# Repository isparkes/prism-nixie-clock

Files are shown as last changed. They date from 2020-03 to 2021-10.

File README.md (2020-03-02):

# Prism Large Tube Nixie Clock
This is the board design for the "Prism" 6-digit Nixie Clock based on the ESP-8266 with NeoPixel LED backlights

## Links
This code comes from:       https://bitbucket.org/isparkes/prism-firmware/
The Hardware:               https://bitbucket.org/isparkes/prism-direct-drive-in-18/

My Shop:                    https://www.nixieclock.biz/Store.html
Manuals:                    https://www.nixieclock.biz/Manuals.html

#### Features:
- Open source Hard and Software 
- Internet connected with the ESP8266
- Real Time Clock interface for backup
- Configuration stored in EEPROM
- RGB Back lighting
- Automatic linear dimming using light sensor

**Instruction and User Manuals (including schematic) can be found at:** [https://www.nixieclock.biz/Manuals.html](https://www.nixieclock.biz/Manuals.html)

You can buy this from: [https://www.nixieclock.biz/Store.html](https://www.nixieclock.biz/Store.html)

YouTube channel: [Ian's YouTube Channel](https://www.youtube.com/channel/UCiC34G8yl0mN2BK-LzPw0ew?view_as=subscriber)

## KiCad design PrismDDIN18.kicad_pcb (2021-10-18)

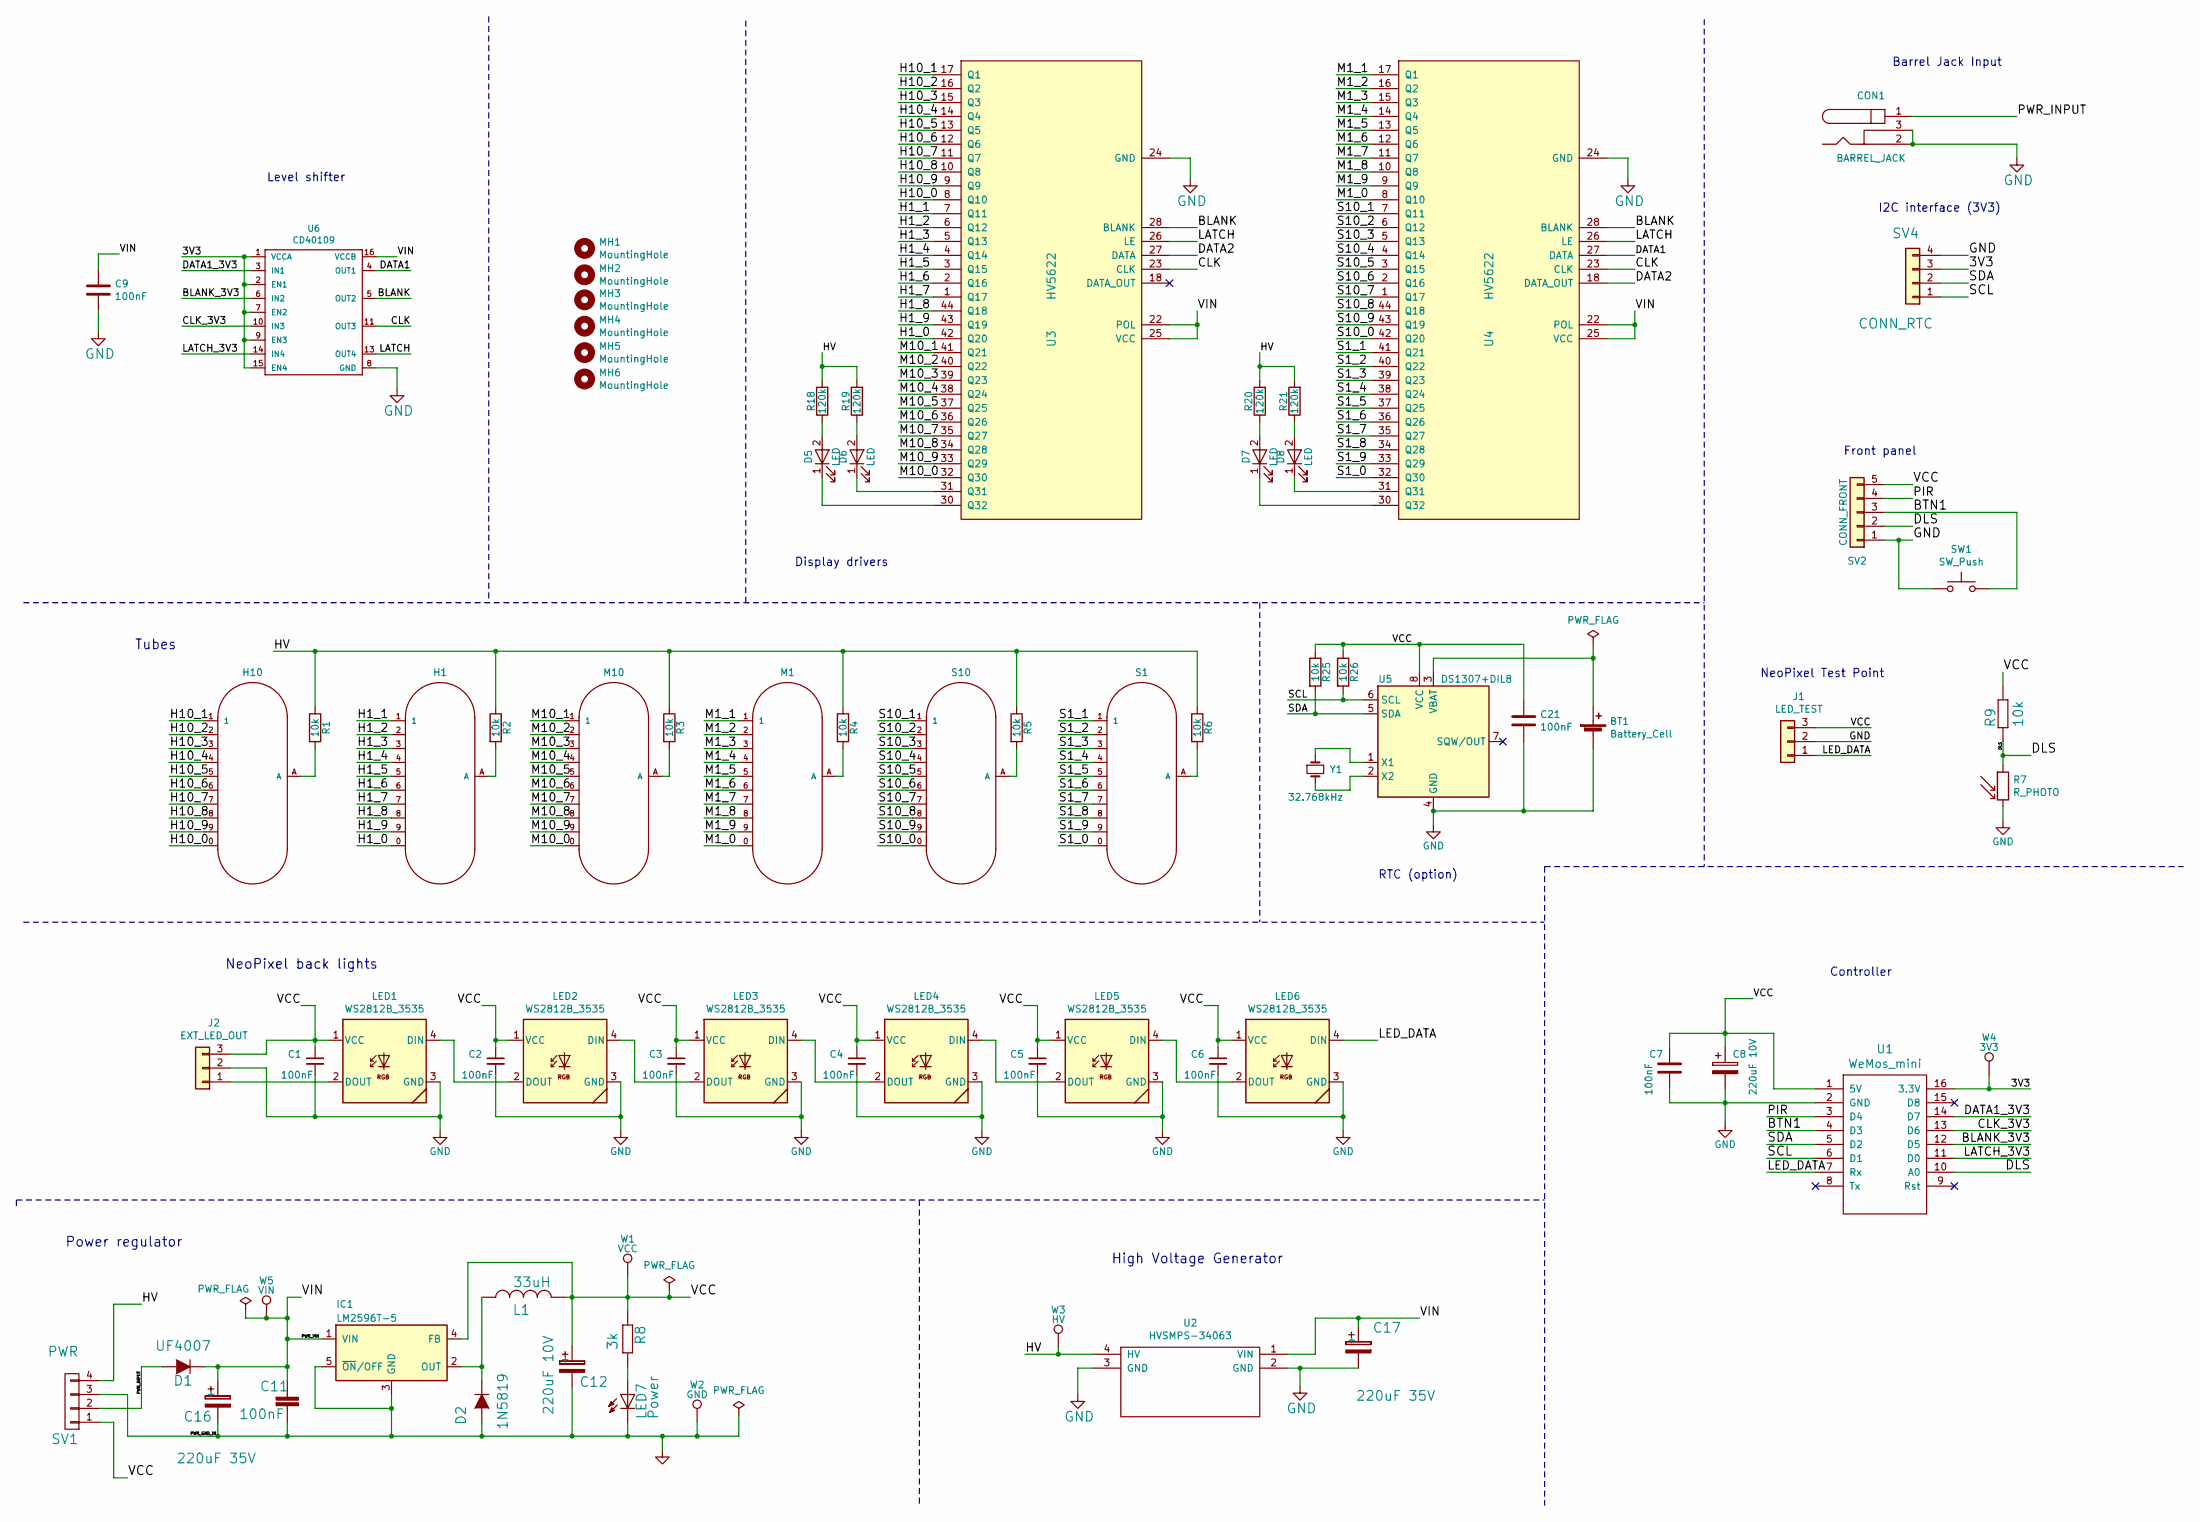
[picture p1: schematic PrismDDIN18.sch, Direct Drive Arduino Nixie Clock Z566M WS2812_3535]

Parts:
BT1: Battery_Cell; CR1220-CoinCell
C1, C2, C3, C4, C5, C6: 100nF; C_1206_3216Metric
C7, C9, C11, C21: 100nF; C025-024X044
C8, C12: 220uF 10V; C_Radial_D6.3_L11.2_P2.5
C16, C17: 220uF 35V; C_Radial_D6.3_L11.2_P2.5
CON1: BARREL_JACK
D1: UF4007; Diode_DO-41_1N4001
D2: 1N5819; Diode_DO-41_1N4001
D5, D6, D7, D8: LED; LED-5MM-Centred
H1, H10: Z566M; IN-18-standoff-pins
IC1: LM2596T-5; TO220-5A_H
J1: LED_TEST; Header_MA03-1_Small
J2: EXT_LED_OUT; Header_MA03-1_Small
L1: 33uH; Inductor-33mH-TH-SMD
LED1, LED2, LED3, LED4, LED5, LED6: WS2812B_3535; WS2812B-SmallPads
LED7: Power; LED_3MM
M1, M10: Z566M; IN-18-standoff-pins
MH1, MH2, MH3, MH4, MH5, MH6: MountingHole; MountingHole_3.2mm_M3
R1, R2, R3, R4, R5, R6: 10k; R_Short_P7.62mm_Horizontal
R7: R_PHOTO; C_Naked
R8: 3k; R-0207_2V
R9, R25, R26: 10k; R-0207_2V
R18, R19, R20, R21: 120k; R_Short_P7.62mm_Horizontal
S1, S10: Z566M; IN-18-standoff-pins
SV1: PWR; Header_MA04-1
SV2: CONN_FRONT; Header_MA05-1
SV4: CONN_RTC; Header_MA04-1
SW1: SW_Push; SW_SPST_CK_RS282G05A3
U1: WeMos_mini; WeMos_D1_mini_board_simple
U2: HVSMPS-34063
U3, U4: HV5622; PLCC44
U5: DS1307+DIL8; DIP-8_W7.62mm
U6: CD40109; DIP-16_W7.62mm
W1: VCC; TESTPAD_P1-13
W2: GND; TESTPAD_P1-13
W3: HV; TESTPAD_P1-13
W4: 3V3; TESTPAD_P1-13
W5: VIN; TESTPAD_P1-13
Y1: 32.768kHz; Crystal_DS10_d1.0mm_l4.3mm_Horizontal

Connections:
/3V3: SV4.3, U1.16 (3.3V), U6.1 (VCCA), U6.2 (EN1), U6.7 (EN2), U6.9 (EN3), U6.15 (EN4), W4.1
/BLANK: U3.28 (BLANK), U4.28 (BLANK), U6.5 (OUT2)
/BLANK_3V3: U1.12 (D5), U6.6 (IN2)
/BTN1: SV2.3, SW1.2, U1.4 (D3)
/CLK: U3.23 (CLK), U4.23 (CLK), U6.11 (OUT3)
/CLK_3V3: U1.13 (D6), U6.10 (IN3)
/DATA1: U4.27 (DATA), U6.4 (OUT1)
/DATA1_3V3: U1.14 (D7), U6.3 (IN1)
/DATA2: U3.27 (DATA), U4.18 (DATA_OUT)
/DLS: R7.1, R9.1, SV2.2, U1.10 (A0)
/H1_0: H1.0, U3.42 (Q20)
/H1_1: H1.1, U3.7 (Q11)
/H1_2: H1.2, U3.6 (Q12)
/H1_3: H1.3, U3.5 (Q13)
/H1_4: H1.4, U3.4 (Q14)
/H1_5: H1.5, U3.3 (Q15)
/H1_6: H1.6, U3.2 (Q16)
/H1_7: H1.7, U3.1 (Q17)
/H1_8: H1.8, U3.44 (Q18)
/H1_9: H1.9, U3.43 (Q19)
/H10_0: H10.0, U3.8 (Q10)
/H10_1: H10.1, U3.17 (Q1)
/H10_2: H10.2, U3.16 (Q2)
/H10_3: H10.3, U3.15 (Q3)
/H10_4: H10.4, U3.14 (Q4)
/H10_5: H10.5, U3.13 (Q5)
/H10_6: H10.6, U3.12 (Q6)
/H10_7: H10.7, U3.11 (Q7)
/H10_8: H10.8, U3.10 (Q8)
/H10_9: H10.9, U3.9 (Q9)
/HV: R1.1, R2.1, R3.1, R4.1, R5.1, R6.1, R18.2, R19.2, R20.2, R21.2, SV1.4, U2.4 (HV), W3.1
/LATCH: U3.26 (LE), U4.26 (LE), U6.13 (OUT4)
/LATCH_3V3: U1.11 (D0), U6.14 (IN4)
/LED_DATA: J1.1, LED6.4 (DIN), U1.7 (Rx)
/M1_0: M1.0, U4.8 (Q10)
/M1_1: M1.1, U4.17 (Q1)
/M1_2: M1.2, U4.16 (Q2)
/M1_3: M1.3, U4.15 (Q3)
/M1_4: M1.4, U4.14 (Q4)
/M1_5: M1.5, U4.13 (Q5)
/M1_6: M1.6, U4.12 (Q6)
/M1_7: M1.7, U4.11 (Q7)
/M1_8: M1.8, U4.10 (Q8)
/M1_9: M1.9, U4.9 (Q9)
/M10_0: M10.0, U3.32 (Q30)
/M10_1: M10.1, U3.41 (Q21)
/M10_2: M10.2, U3.40 (Q22)
/M10_3: M10.3, U3.39 (Q23)
/M10_4: M10.4, U3.38 (Q24)
/M10_5: M10.5, U3.37 (Q25)
/M10_6: M10.6, U3.36 (Q26)
/M10_7: M10.7, U3.35 (Q27)
/M10_8: M10.8, U3.34 (Q28)
/M10_9: M10.9, U3.33 (Q29)
/PIR: SV2.4, U1.3 (D4)
/PWR_INPUT: CON1.1, D1.2 (A), SV1.2
/PWR_VIN: C9.1, C11.2, C16.1, C17.1, D1.1 (K), IC1.1 (VIN), U2.1 (VIN), U3.22 (POL), U3.25 (VCC), U4.22 (POL), U4.25 (VCC), U6.16 (VCCB), W5.1
/S1_0: S1.0, U4.32 (Q30)
/S1_1: S1.1, U4.41 (Q21)
/S1_2: S1.2, U4.40 (Q22)
/S1_3: S1.3, U4.39 (Q23)
/S1_4: S1.4, U4.38 (Q24)
/S1_5: S1.5, U4.37 (Q25)
/S1_6: S1.6, U4.36 (Q26)
/S1_7: S1.7, U4.35 (Q27)
/S1_8: S1.8, U4.34 (Q28)
/S1_9: S1.9, U4.33 (Q29)
/S10_0: S10.0, U4.42 (Q20)
/S10_1: S10.1, U4.7 (Q11)
/S10_2: S10.2, U4.6 (Q12)
/S10_3: S10.3, U4.5 (Q13)
/S10_4: S10.4, U4.4 (Q14)
/S10_5: S10.5, U4.3 (Q15)
/S10_6: S10.6, U4.2 (Q16)
/S10_7: S10.7, U4.1 (Q17)
/S10_8: S10.8, U4.44 (Q18)
/S10_9: S10.9, U4.43 (Q19)
/SCL: R26.2, SV4.1, U1.6 (D1), U5.6 (SCL)
/SDA: R25.2, SV4.2, U1.5 (D2), U5.5 (SDA)
/VCC: C1.1, C2.1, C3.1, C4.1, C5.1, C6.1, C7.1, C8.1, C12.1, C21.1, IC1.4 (FB), J1.3, J2.3, L1.2, LED1.1 (VCC), LED2.1 (VCC), LED3.1 (VCC), LED4.1 (VCC), LED5.1 (VCC), LED6.1 (VCC), R8.1, R9.2, R25.1, R26.1, SV1.1, SV2.5, U1.1 (5V), U5.8 (VCC), W1.1
GND: BT1.2 (-), C1.2, C2.2, C3.2, C4.2, C5.2, C6.2, C7.2, C8.2, C9.2, C11.1, C12.2, C16.2, C17.2, C21.2, CON1.2, CON1.3, D2.2 (A), IC1.3 (GND), IC1.5 (~ON~/OFF), J1.2, J2.2, LED1.3 (GND), LED2.3 (GND), LED3.3 (GND), LED4.3 (GND), LED5.3 (GND), LED6.3 (GND), LED7.K (C), R7.2, SV1.3, SV2.1, SV4.4, SW1.1, U1.2 (GND), U2.2 (GND), U2.3 (GND), U3.24 (GND), U4.24 (GND), U5.4 (GND), U6.8 (GND), W2.1
unnamed: BT1.1 (+), U5.3 (VBAT)
unnamed: D2.1 (K), IC1.2 (OUT), L1.1
unnamed: D5.1 (K), U3.30 (Q32)
unnamed: D5.2 (A), R18.1
unnamed: D6.1 (K), U3.31 (Q31)
unnamed: D6.2 (A), R19.1
unnamed: D7.1 (K), U4.30 (Q32)
unnamed: D7.2 (A), R20.1
unnamed: D8.1 (K), U4.31 (Q31)
unnamed: D8.2 (A), R21.1
unnamed: H1.A, R2.2
unnamed: H10.A, R1.2
unnamed: J2.1, LED1.2 (DOUT)
unnamed: LED1.4 (DIN), LED2.2 (DOUT)
unnamed: LED2.4 (DIN), LED3.2 (DOUT)
unnamed: LED3.4 (DIN), LED4.2 (DOUT)
unnamed: LED4.4 (DIN), LED5.2 (DOUT)
unnamed: LED5.4 (DIN), LED6.2 (DOUT)
unnamed: LED7.A, R8.2
unnamed: M1.A, R4.2
unnamed: M10.A, R3.2
unnamed: R5.2, S10.A
unnamed: R6.2, S1.A
unnamed: U5.1 (X1), Y1.1
unnamed: U5.2 (X2), Y1.2

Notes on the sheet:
Power regulator
RTC (option)
Barrel Jack Input
High Voltage Generator
NeoPixel back lights
Tubes
Display drivers
I2C interface (3V3)
Front panel
NeoPixel Test Point
Level shifter
Controller

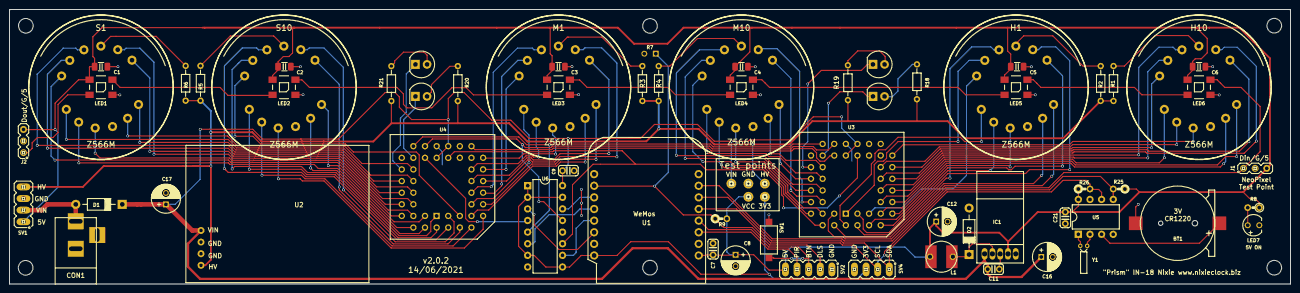
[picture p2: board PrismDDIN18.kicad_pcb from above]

Board: 2 copper layers, 280.0 x 60.0 mm, 76 parts (1 on the bottom side), 106 nets.

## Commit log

2018-11-11 First version
    [PrismDDIN18.dsn, PrismDDIN18.kicad_pcb, PrismDDIN18.sch]
2018-11-22 Update to KiCAD 5, re-space
    [PrismDDIN18.kicad_pcb, PrismDDIN18.sch]
2018-11-22 Shrink board to 280x60
    [PrismDDIN18.kicad_pcb]
2018-11-23 Added DS1307, re-laid out HV
    [PrismDDIN18.kicad_pcb, PrismDDIN18.sch]
2018-11-23 Align tubes, add mounting holes
    [PrismDDIN18.kicad_pcb]
2018-11-24 Initial Wemos version
    [PrismDDIN18.kicad_pcb]
2018-11-25 Improve VCC and HV layout
    [PrismDDIN18.kicad_pcb, PrismDDIN18.sch]
2018-11-25 More minor improvements
    [PrismDDIN18.kicad_pcb, PrismDDIN18.sch]
2018-11-25 "Balance" HV chips
    [PrismDDIN18.kicad_pcb]
2018-11-26 Update IN-18 footprints, define RV1 value
    [PrismDDIN18.kicad_pcb, PrismDDIN18.sch]
2018-12-12 Re-center connections to tubes
    [PrismDDIN18.kicad_pcb]
2018-12-12 Add 3V3 test point, move test points
    [PrismDDIN18.kicad_pcb, PrismDDIN18.sch]
2018-12-20 Add I2C pullups
    [PrismDDIN18.kicad_pcb, PrismDDIN18.sch]
2019-01-04 Minor adjustments to level shifter placings
    [PrismDDIN18.kicad_pcb]
2019-02-07 Correct 2N3906 pin out
    [PrismDDIN18.kicad_pcb, PrismDDIN18.sch]
2019-02-26 Update component values
    [PrismDDIN18.sch]
2019-02-26 Add centre mouting hole
    [PrismDDIN18.kicad_pcb]
2019-02-26 Update netlist, bodard date
    [PrismDDIN18.kicad_pcb]
2019-08-28 correct LV inductor value
    [PrismDDIN18.sch]
2019-08-28 Contribution from Hartmut with sk6812 mini
    [PrismDDIN18.kicad_pcb, PrismDDIN18.sch]
2020-01-31 Use APA106
    [PinLocationsIN18.ods, PrismDDIN18.kicad_pcb, PrismDDIN18.sch]
2021-06-16 Update to new layout
    [Positions.ods, PrismDDIN18.kicad_pcb, PrismDDIN18.sch]
2021-10-05 Rotate tubes
    [PrismDDIN18.kicad_pcb]
2021-10-17 Change pin size of socket, swap D0 and D5 for PWM blanking
    [PrismDDIN18.kicad_pcb, PrismDDIN18.sch]
2021-10-18 Prepare for FAB
    [PrismDDIN18.kicad_pcb]
